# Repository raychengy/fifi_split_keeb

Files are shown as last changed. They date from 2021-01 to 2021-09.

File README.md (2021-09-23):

# Fifi Keyboard 🐶 ⌨️
- [Fifi Keyboard](#fifi-keyboard-🐶-⌨️)
  - [TODO](#todo)
  - [Bill of Materials (BOM)](docs/BOM.md)
  - [Building Instructions](docs/BuildInstructions.md)
    - [Build Keyboard](docs/BuildInstructions.md#build-keyboard)
    - [Build Firmware](docs/BuildInstructions.md#build-firmware)

The Fifi keyboard, named after my [🐶](assets/fifi.gif), is a split keyboard with 3x5 column staggered keys and 3 thumb keys, based on foostan's mini-[crkbd](https://github.com/foostan/crkbd/) schematic and thomasbaart's [kyria](https://github.com/splitkb/kyria) layout.

fifi Split Keyboard

The goal of this project was to build a split keyboard that fits perfectly for the [miryoku](https://github.com/manna-harbour/miryoku) layout with the minimalist style of mini-crkbd and have the aggressive column staggered keys found in kyria. The PCB is reversible, meaning you'll need two of the same PCB to create a full keyboard. It is my first attempt in PCB board design.

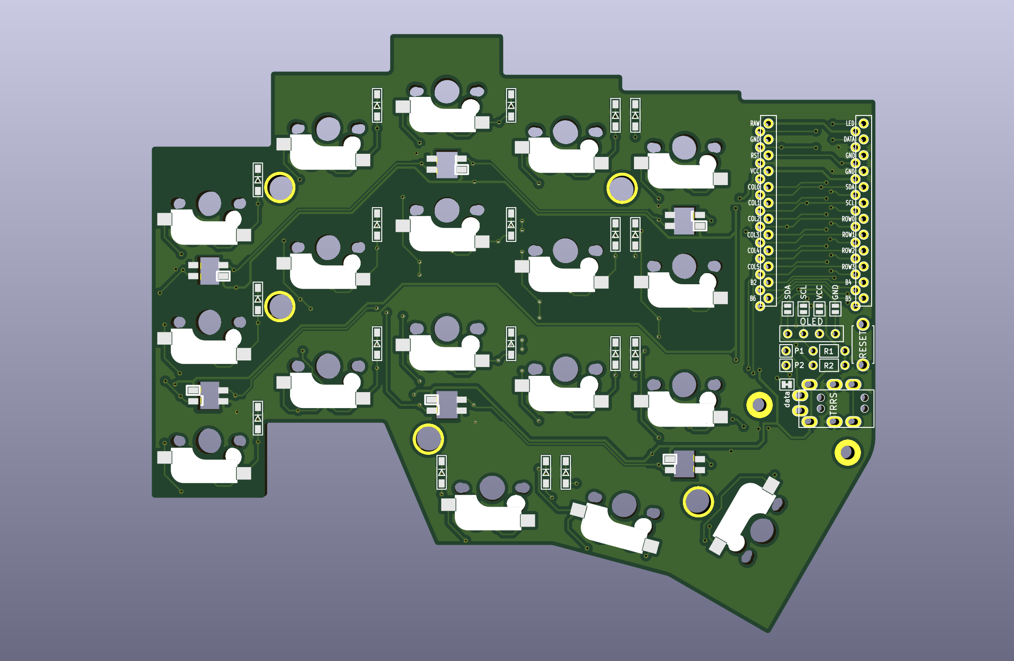
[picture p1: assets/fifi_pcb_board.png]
fifi PBC Board


## TODO
- Add tent puck support
- Add an additional key in the thumb cluster (support for rotorary encoder)
- Add 3D-printed case

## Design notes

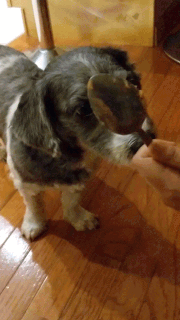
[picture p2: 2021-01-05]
assets/fifi.gif

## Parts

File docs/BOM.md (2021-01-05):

# Bill of Materials (BOM)
| Item | Quanity | Comments |
|:---|:---:|---|
| Micro-controllers | 2 | Mix-and-Match between Elite-C and Pro-Micro controllers |
| PCB | 2 | |
| Diodes | 36 | [1N4148WTR](https://www.digikey.com/product-detail/en/smc-diode-solutions/1N4148WTR/1655-1360-1-ND/6022805) SOD123 will work |
| Kailh MX Hot Swapping Socket  | 36 |
| Tactile Switches | 2 | Outline dimensions 6.00mm x 3.50mm |
| TRRS Jacks | 2 | |
| MX Key Switches | 36 | |
| Keycaps | 36 | 1u x 34, 1.5u x 2 |
| 12-Position Socket Header | 4 | **Optional** - Allowing hot-swapping micro-controller|
| 4-Position Socket Header | 2 | **Optional** - Allowing hot-swapping OLED |
| 128x32 OLED Screen | 2 | **Optional** - Allowing OLED displays |
| SK6812MINI LEDs | 12 | **Optional** - Adds underglow RGB display |
| TRRS Cable | 1 | |
| Top-Plate | 2 | **Note**: Top plate was cut from FR4 material, same as the PCB |
| Bottom-Plate | 2 | **Note**: Bottom plate was cut from a frosted acrylic sheet to diffuse underglow LEDs |
| LED Guard | 2 | |
| Spacer M2x8mm | 10 | |
| Screw M2x6mm | 20 | |
| Rubber bumbers | 8-10  | |

[[Back to README]](../README.md)

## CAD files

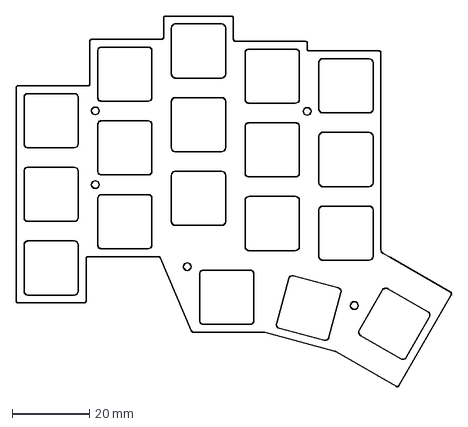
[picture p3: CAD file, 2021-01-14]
plates/top-plate.dxf
112.6 x 95.9 mm

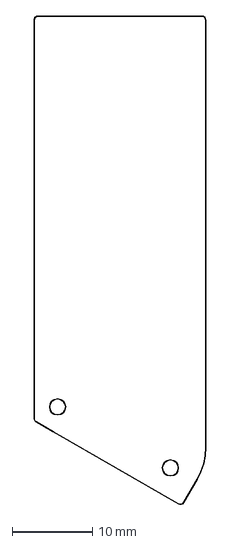
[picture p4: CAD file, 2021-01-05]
plates/lcd-guard.dxf
21.4 x 61.0 mm

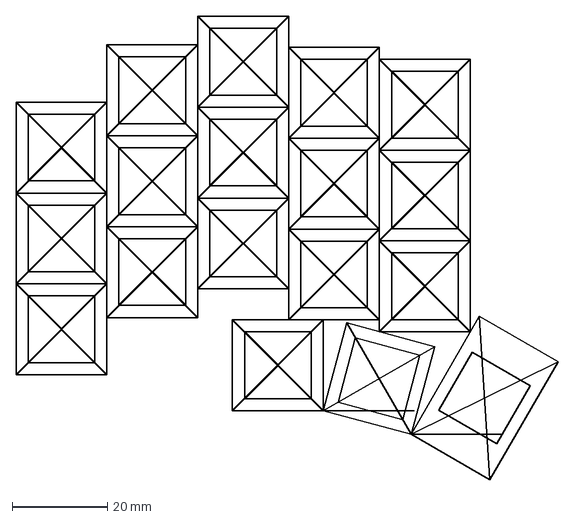
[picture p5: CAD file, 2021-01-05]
plates/key-positions.dxf
113.6 x 97.2 mm

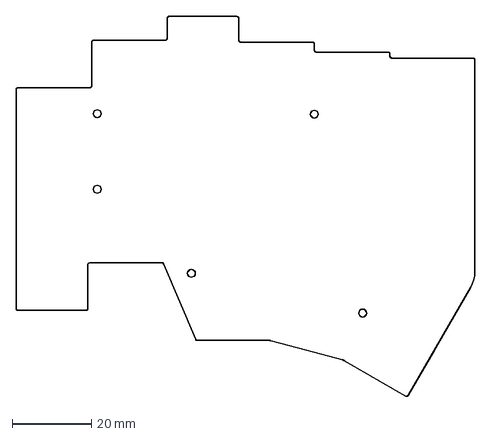
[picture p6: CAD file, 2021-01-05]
plates/bottom-plate.dxf
115.7 x 95.9 mm

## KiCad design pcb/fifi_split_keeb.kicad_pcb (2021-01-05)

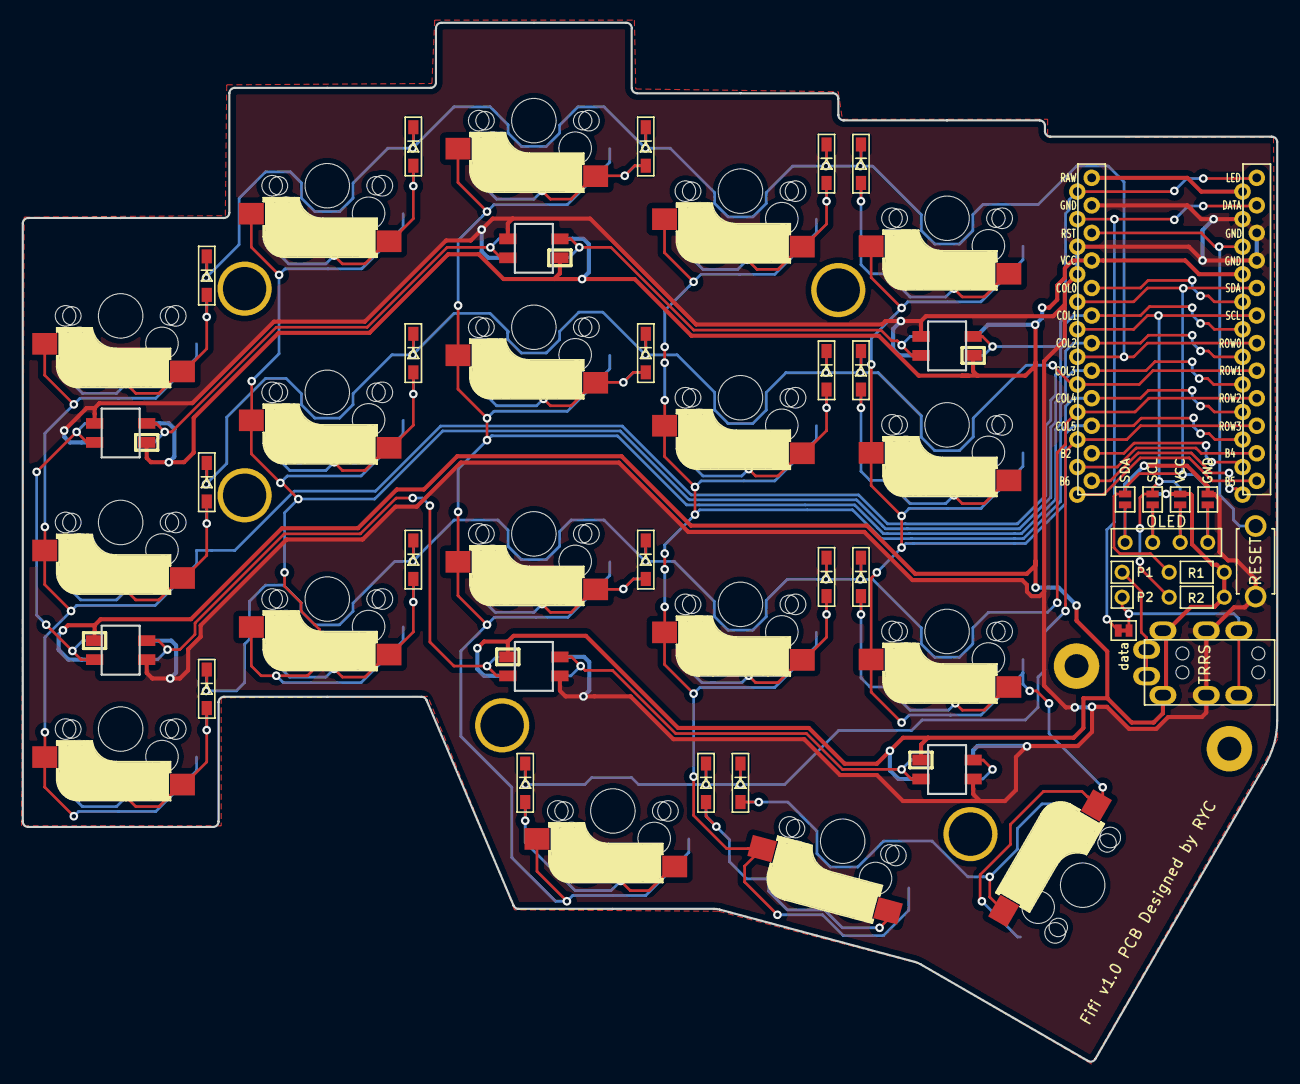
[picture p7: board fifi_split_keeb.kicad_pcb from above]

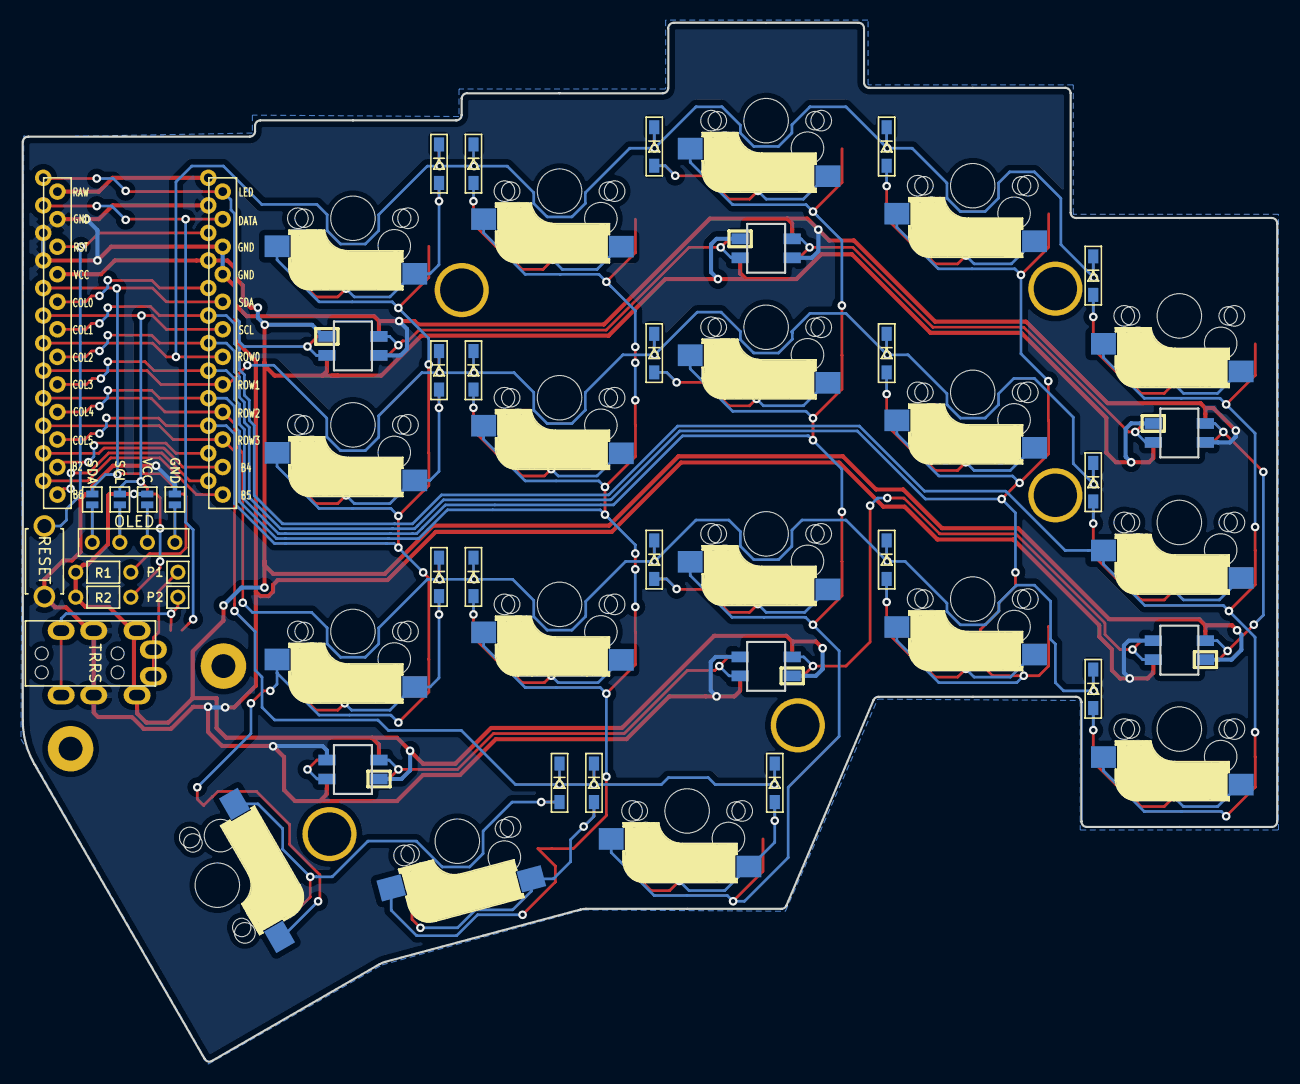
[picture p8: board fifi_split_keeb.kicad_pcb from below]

Board: 2 copper layers, 115.7 x 95.8 mm, 59 parts (4 on the bottom side), 45 nets.

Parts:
D1, D2, D3, D4, D5, D6, D7, D8, D9, D10, D11, D12, D13, D14, D15, D16, D17, D18: D; D3_SMD
J1: TRRS-Barrel; MJ-4PP-9
J2: OLED
JP1, JP8: GND; Jumper
JP2, JP7: VCC; Jumper
JP3, JP6: SCL; Jumper
JP4, JP5: SDA; Jumper
JP9: data; JPC2
L19, L20, L21, L22, L23, L24: SK6812MINI; SK6812MINI_rev
P1, P2: i2c-pin; 1pin_conn
R1, R2: R
RSW1: SW_PUSH; ResetSW
SW1, SW2, SW3, SW4, SW5, SW6, SW7, SW8, SW9, SW10, SW11, SW12, SW13, SW14, SW15, SW16, SW17: SW_PUSH; CherryMX_MidHeight_Hotswap
SW18: SW_PUSH; CherryMX_MidHeight_Hotswap_1.5u
U1: ProMicro; ProMicro_v2

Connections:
GND: J1.C, JP1.2, JP8.2, L19.2, L20.2, L21.2, L22.2, L23.2, L24.2, RSW1.2, U1.3, U1.4, U1.23
LED: L21.3, U1.1
unnamed: D1.2, SW1.2
unnamed: D2.2, SW2.2
unnamed: D3.2, SW3.2
unnamed: D4.2, SW4.2
unnamed: D5.2, SW5.2
unnamed: D6.2, SW6.2
unnamed: D7.2, SW7.2
unnamed: D8.2, SW8.2
unnamed: D9.2, SW9.2
unnamed: D10.2, SW10.2
unnamed: D11.2, SW11.2
unnamed: D12.2, SW12.2
unnamed: D13.2, SW13.2
unnamed: D14.2, SW14.2
unnamed: D15.2, SW15.2
unnamed: D16.2, SW16.2
unnamed: D17.2, SW17.2
unnamed: D18.2, SW18.2
unnamed: J1.A, P1.1
unnamed: J1.B, JP9.2, P2.1
unnamed: J2.1, JP4.1, JP8.1
unnamed: J2.2, JP3.1, JP7.1
unnamed: J2.3, JP2.1, JP6.1
unnamed: J2.4, JP1.1, JP5.1
unnamed: L19.1, L22.3
unnamed: L19.3, L20.1
unnamed: L20.3, L21.1
unnamed: L22.1, L23.3
unnamed: L23.1, L24.3
SCL: JP3.2, JP6.2, R2.2, U1.6
SDA: JP4.2, JP5.2, R1.2, U1.5
VCC: J1.D, JP2.2, JP7.2, L19.4, L20.4, L21.4, L22.4, L23.4, L24.4, R1.1, R2.1, U1.21
col0: SW1.1, SW6.1, SW11.1, U1.19
col1: SW2.1, SW7.1, SW12.1, U1.18
col2: SW3.1, SW8.1, SW13.1, SW16.1, U1.17
col3: SW4.1, SW9.1, SW14.1, SW17.1, U1.16
col4: SW5.1, SW10.1, SW15.1, SW18.1, U1.15
data: JP9.1, U1.2
reset: RSW1.1, U1.22
row0: D1.1, D2.1, D3.1, D4.1, D5.1, U1.7
row1: D6.1, D7.1, D8.1, D9.1, D10.1, U1.8
row2: D11.1, D12.1, D13.1, D14.1, D15.1, U1.9
row3: D16.1, D17.1, D18.1, U1.10

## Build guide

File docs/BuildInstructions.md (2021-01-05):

# Build Instructions

- [Build Keyboard](#build-keyboard)
  - [Solder Diodes](#solder-diodes)
  - [Solder Underglow LEDs](#solder-underglow-leds)
  - [Solder Reset Switch, TRRS Jack, and OLED header](#solder-reset-switch,-trrs-jack,-and-oled-header)
  - [Solder OLED jumpers](#solder-oled-jumpers)
  - [Solder Microcontroller](#solder-micro-controller)
  - [Solder OLED Display](#solder-oled-display)
- [Build Firmware](#build-firmware)
  - [QMK Setup](#qmk-setup)
  - [Building miryoku layout firmware](#building-miryoku-layout-firmware)

## Build Keyboard

### Solder diodes
Best to solder the diodes onto the underside of each PCB.

The orientation of the diode is as follows. The line mark on each diode will match the line mark on the silk screen.

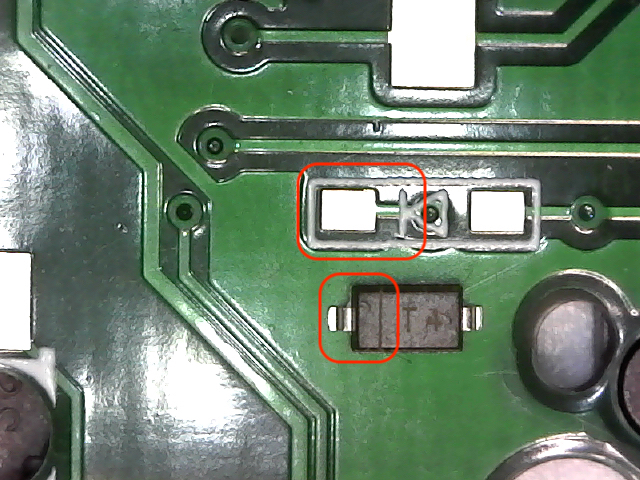
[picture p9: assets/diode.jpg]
Zoomed in view of diode aligned with PCB diode pads


The trick is to tin each of the PCB diode's right pad. When ready, melt the tinned pad with the iron and using a tweezer slide the diode in place. It's recommended that you use a reverse tweezer to avoid apply excessive force.

Afterwards solder the other pad. A small amount of solder should suffice. If there is excessive amount of solder, remove it with suction pump or soldering wick.

### Solder Underglow LEDs

The orientation of the LED is as follows. The square shape lead on the back of each LED will match the square outline mark on the silk screen.

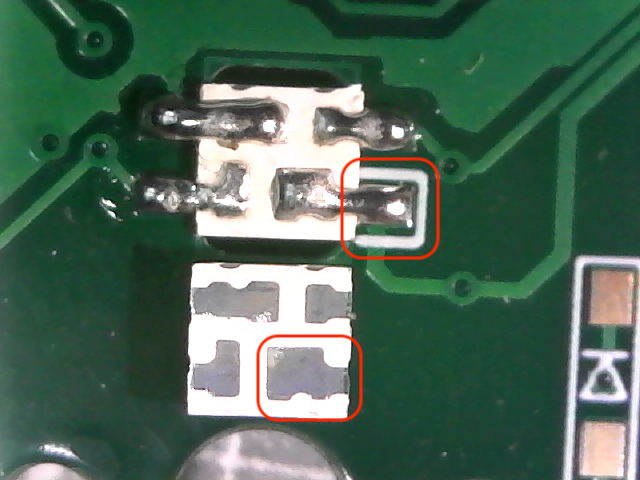
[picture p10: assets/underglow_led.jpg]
Zoomed in view of the LED aligned with the PCB LED pads


Best to set the soldering iron at a low temperature 475 degrees Fahrenheit to avoid burning the LED. Avoid long contact with the LEDs. You can potentially burn the current or the neighboring LEDs.

Here is a [video](https://twitter.com/foostan/status/1005656803818889216) of foostan soldering the LED on crkbd.

### Solder OLED jumpers

Bridge the OLED jumper pads on the upper side of each PCB.

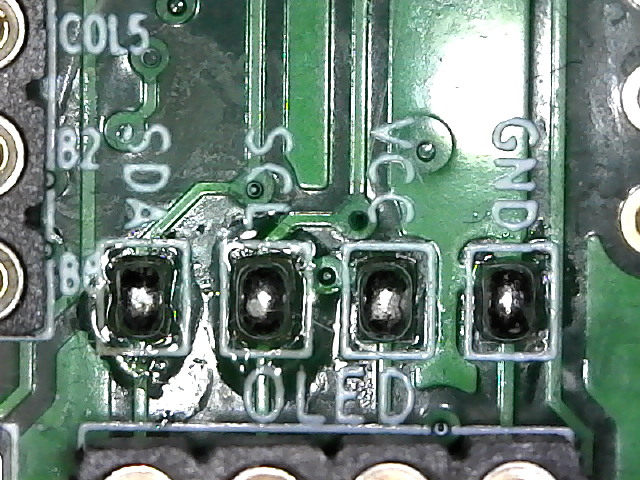
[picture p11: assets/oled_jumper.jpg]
Zoomed in view of the bridged connections


### Solder Reset Switch, TRRS Jack, and OLED header

Solder the reset switch, TRRS jack, and the OLED headers with the components facing on the upperside of each PCB.

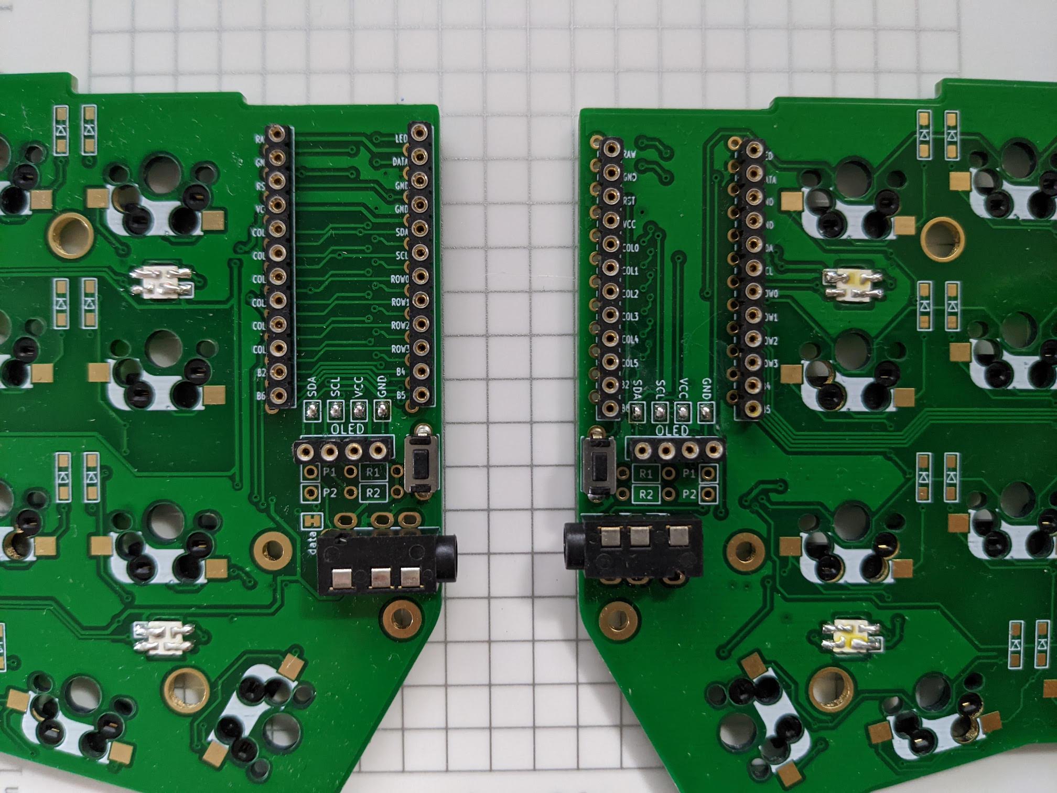
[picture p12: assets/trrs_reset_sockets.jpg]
Overhead view of the PCB board with the reset switches, TRRS jacks, OLED headers soldered


### Solder Microcontroller

**Optional** - Solder some low-profile socket headers on the upper side of each PCB.

Or solder the male header directly to the board.

### Solder OLED Display

**Optional** - Solder some male headers on each OLED displays.

[[Back to README]](../README.md)

## Build Firmware

### QMK Setup

Check out QMK official documentation on [Setting Up Your QMK Environment](https://docs.qmk.fm/#/newbs_getting_started).

[[Back to README]](../README.md)

### Building miryoku layout firmware

Add the Miryoku development branch into your existing QMK build environment.

```
git remote add manna-harbour git@github.com:manna-harbour/qmk_firmware.git
git fetch manna-harbour
git checkout --track manna-harbour/miryoku
```

To build for ProMicros, run:
```
make crkbd:manna-harbour_miryoku:flash
```
To build for Elite-C, run:
```
make crkbd:manna-harbour_miryoku:dfu
```

[[Back to README]](../README.md)

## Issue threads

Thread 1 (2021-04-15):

Tent puck support

mrkskk, 2021-04-15:
Beautiful keyboard. It check al my boxes except tenting support. May i suggest adding support for the splitkb puck?

tommyalatalo, 2021-05-19:
I would also love to see a tenting solution, and the splitkb one is not a bad suggestion

raychengy, 2021-05-20:
I'll have to get a hold of the splitkb puck, but I'll keep the tenting option in my mind.

mrkskk, 2021-05-25:
I believe the ferris and sweep have implemented puck support so it should
be fairly easy to copy the holes. Easy if you know something about pcb
design. Personally I don't yet.

Markus.
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

tommyalatalo, 2021-07-02:
@raychengy I just realized a tip here would be to head over to the splitkb discord and ask Thomas Baart for the tent puck dimensions, that way you don't necessarily have to get one to implement it into the design.

deggers, 2021-07-04:
It's available in some library for kicad, so it's just copy and paste, AFAIK.
I would love puck support as well :)

camrbuss, 2021-08-07:
Pierre put his KiCad footprint [here](https://github.com/pierrechevalier83/keyboard_footprints/tree/master/puck.pretty).

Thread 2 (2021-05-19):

not a issue, but where I can get one ?

agsb, 2021-05-19:

raychengy, 2021-05-20:
At the moment, the only way is to print out the [circuit board](https://github.com/raychengy/fifi_split_keeb/releases/download/fifi-v1.0/fifi-keeb-gerber.zip), the [top-layer](https://github.com/raychengy/fifi_split_keeb/blob/main/plates/top_plate-gerber.zip).

Closed 2022-01-01.

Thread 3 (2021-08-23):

Thickness of bottom and top plate

toniz4, 2021-08-23:
In the BOM there is a mention about the top plate and bottom plate.

If I want to use it without a bottom or top plate, it would be possible? (like a gergoplex)
What would be the apropriate thickness of both of those plates? If I would make them out of arcylic or polycarbonate.

Thanks!

hmngwy, 2021-09-09:
If acrylic, no thinner than 3mm to have sufficient durability. For the switch plate no thicker than 5mm.

toniz4, 2021-09-10:
I'm going to build one with a 3mm acrylic, for the top and bottom plate. When i'm done i will show the results.

rcheng-ns1, 2021-09-23:
@toniz4 sorry for the late reply! 3mm acrylic will work for the top and bottom.

toniz4, 2021-11-07:
Indeed, 3mm acrylic with 6mm bottom/top  plate spacers works perfectly. Thanks!

Closed 2021-11-07.

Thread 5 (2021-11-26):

choc support and TH diode

Shahabaz-Bagwan, 2021-11-26:
can you add choc keyswitch support and through hole diode support

Shahabaz-Bagwan, 2021-11-27:
https://github.com/pashutk/chocofi

I found what I was looking for.

Closed 2021-11-27.

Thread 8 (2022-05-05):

Case options

markstos, 2022-05-05:
I'm starting an issue just to document case options. Here's one made with acrylic and brass plates:

https://github.com/brickbots/FiFi_Case

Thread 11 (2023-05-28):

Mod for increased stability, reduced slippery and reduced noise

Arkanosis, 2023-05-28:
After happily using the Fifi for 10 months with [rubber bumpers](https://fr.aliexpress.com/item/1005003044229837.html), I've switched to [a foam mat](https://fr.aliexpress.com/item/1005004825493264.html) instead.

I've cut the shape of the bottom plate out of the 3.5 mm × 150 mm × 350 mm mat, which gave me 2 keyboards worth of foam (2 left halves and 2 right halves — only one side of the mat has a nonslip surface, so they are not reversible), which I've then glued under the FR4 bottom plates.

I'm pretty happy with the result, which has the following benefits over the rubber bumpers I was using before:
 - increased stability: I was using 5 bumpers per half, but pressing hard on some keys made it pitch a little (this could probably have been fixed with a 6th bumper per half, TBH);
 - reduced slippery: the bumpers were not preventing the halves from slowly moving during long typing sessions (whether the mat will prevent that at it gets dirty remains to be seen);
 - reduced noise: I'm using Gazzew Boba U4 silent tactile switches and most of the remaining noise of the keyboard was from the keys bottoming out, conducted through my wooden desk, and the mat completely prevents that.

The mat being glued under the bottom plates means the keyboard remains as convenient to use as before.

Note: cutting the foam is surprisingly difficult with an utility knife, but easy with a multi purpose shear.

Arkanosis, 2023-05-28:
Some pictures…

Top: silicon rubber bumpers; bottom: polyurethane foam:

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

The screw heads are deep in the foam:

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

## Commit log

2021-01-05 Initial release of fifi keeb with documentations
    [bottom-plate.dxf, fifi_split_keeb.kicad_pcb, fifi_split_keeb.sch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]
2021-01-11 Added github action workflow to build gerber files
2021-01-14 Added top-plate gerber file & updated .dxf file
    [top-plate.dxf]
2021-09-23 Updated readme w/ wishlist & btm plate gerber zip
